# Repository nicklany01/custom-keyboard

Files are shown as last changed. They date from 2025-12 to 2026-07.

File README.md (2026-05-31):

# Custom Keyboard
## Releases
The built program can be found in github actions under the corresponding commit. There will be a file called "fireware.zip" that can be downloaded and flashed to the keyboard.
## Flashing Instructions
1. Connect the keyboard via a USB cable.
2. Double click the reset button on the keyboard (found below the rotary encoder) to enter bootloader mode. The keyboard should show up as a mass storage device on your computer.
3. Copy the "firmware.uf2" file from the downloaded release to the mass storage device to flash the keyboard. The storage device should automatically eject and the keyboard will reboot with the new firmware.
## Local Build Instructions
Source code is built in github actions using the ZMK firmware framework. To build the firmware locally, follow these steps:
1. Clone the ZMK repository using the following command:
```
git clone https://github.com/zmkfirmware/zmk.git
```
2. Set up the Zephyr SDK as described [here](https://docs.zephyrproject.org/3.5.0/develop/getting_started/index.html)
3. From the zmk directory, run the following commands to build the firmware, ensuring to replace "/path/to/this/repo/config" with the path to the config directory in this repository:
```
cd app
# To build the left side:
west build -p -b nice_nano@2.0.0 -- -DSHIELD="chirality_left nice_view_gem" -DZMK_CONFIG=/path/to/this/repo/config

# To build the right side:
west build -p -b nice_nano@2.0.0 -- -DSHIELD="chirality_right nice_view_gem" -DZMK_CONFIG=/path/to/this/repo/config
```
The built firmware file can be found at "/path/to/zmk/app/build/zephyr/zmk.uf2", and can be flashed with the [flash instructions](#flashing-instructions) above, treating "zmk.uf2" as "firmware.uf2".
For more information, see the [ZMK documentation](https://zmk.dev/docs/development/local-toolchain/setup/native) and [Zephyr documentation](https://docs.zephyrproject.org/3.5.0/develop/getting_started/index.html)

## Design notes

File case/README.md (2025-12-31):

# Case Implementation
This case is built with build123d and viewed with ocp_vscode.
## 1. Install
```bash
pip install build123d ocp_vscode
```

## 2. Start Viewer
*Ignore this section if using the OCP VSCode extension.*
Run this once to start the server in a detached tmux session:
```bash
tmux new -s viewer -d 'python -m ocp_vscode'
```
Open browser to: `http://127.0.0.1:3939`
*Note: other options are to use screen, run in background with &, suspend with ctrl z and send to background using bg, or use another terminal.*

## 3. Usage
### Dependencies
Make sure svg files required exist by running:
```sh
./case/src/export_assets.sh
```

### Run
Run the following command to update the viewer and export the build files:
```sh
python case/src/top_plate.py [-h] [--side [{left,right}]] [--thickness THICKNESS] [--extras | --no-extras] [--show | --no-show]

```

## 4. Commands
* **Run script:** `python main.py` (updates viewer)
* **Check logs:** `tmux attach -t viewer`
* **Kill server:** `tmux kill-session -t viewer`

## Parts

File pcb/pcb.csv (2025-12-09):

Reference | Qty | Value | DNP | Exclude from BOM | Exclude from Board | Footprint | Datasheet
C1,C2,C3,C4 | 4 | 100n |  |  |  | Custom Footprints:0805_2012_nonpolarised | ~
D1,D2,D3,D4,D5,D6,D7,D8,D9,D10,D11,D12,D13,D14,D15,D16,D17,D18,D19,D38,D39,D40,D41,D42,D43,D44,D45,D46,D47,D48,D49,D50,D51,D52,D53,D54,D55,D56 | 38 | 1N4148WT |  |  |  | Custom Footprints:D_SOD-523 | https://www.diodes.com/assets/Datasheets/ds30396.pdf
D20,D21,D22,D23,D24,D25,D26,D27,D28,D29,D30,D31,D32,D33,D34,D35,D36,D37,D57,D58,D59,D60,D61,D62,D63,D64,D65,D66,D67,D68,D69,D70,D71,D72,D73,D74 | 36 | SK6812 |  |  |  | Custom Footprints:SK6812_4020_SIDE_rev2 | https://cdn-shop.adafruit.com/product-files/1138/SK6812+LED+datasheet+.pdf
Display1,Display2 | 2 | nice!view |  |  |  | Custom_Footprints:nice_view | https://nicekeyboards.com/docs/nice-view/pinout-schematic
F1,F2 | 2 | Polyfuse |  |  |  | Custom Footprints:0805_2012_nonpolarised | ~
J1,J2 | 2 | Conn_01x02_Socket |  |  |  | Custom Footprints:JST_PH_S2B-PH-SM4-TB_1x02-1MP_P2.00mm_Horizontal | ~
PSW1,PSW2 | 2 | SW_SPST |  |  |  | Custom_Footprints:SW_SPDT_PCM12 | https://www.nidec-components.com/e/catalog/switch/cas.pdf
Q1,Q2 | 2 | 2N7002 |  |  |  | Custom Footprints:SOT-23-3 | https://www.onsemi.com/pub/Collateral/NDS7002A-D.PDF
R1,R2 | 2 | 100k |  |  |  | Custom Footprints:0805_2012_nonpolarised | ~
RSW1,RSW2 | 2 | SW_Push |  |  |  | Custom Footprints:SW_SPST_FSMSM | ~
SW1,SW2,SW3,SW4,SW5,SW6,SW7,SW8,SW9,SW10,SW11,SW12,SW13,SW14,SW15,SW16,SW17,SW18,SW20,SW21,SW22,SW23,SW24,SW25,SW26,SW27,SW28,SW29,SW30,SW31,SW32,SW33,SW34,SW35,SW36,SW37 | 36 | SW_Push |  |  |  | Custom Footprints:gateron-ks27-hotswap-reversible | ~
SW19,SW38 | 2 | RotaryEncoder_Switch |  |  |  | Custom Footprints:RotaryEncoder_Alps_EC11E-Switch_Vertical_H20mm | ~
U1,U2 | 2 | Sparkfun_Pro_Micro |  |  |  | Arduino:Sparkfun_Pro_Micro | https://www.sparkfun.com/products/12640

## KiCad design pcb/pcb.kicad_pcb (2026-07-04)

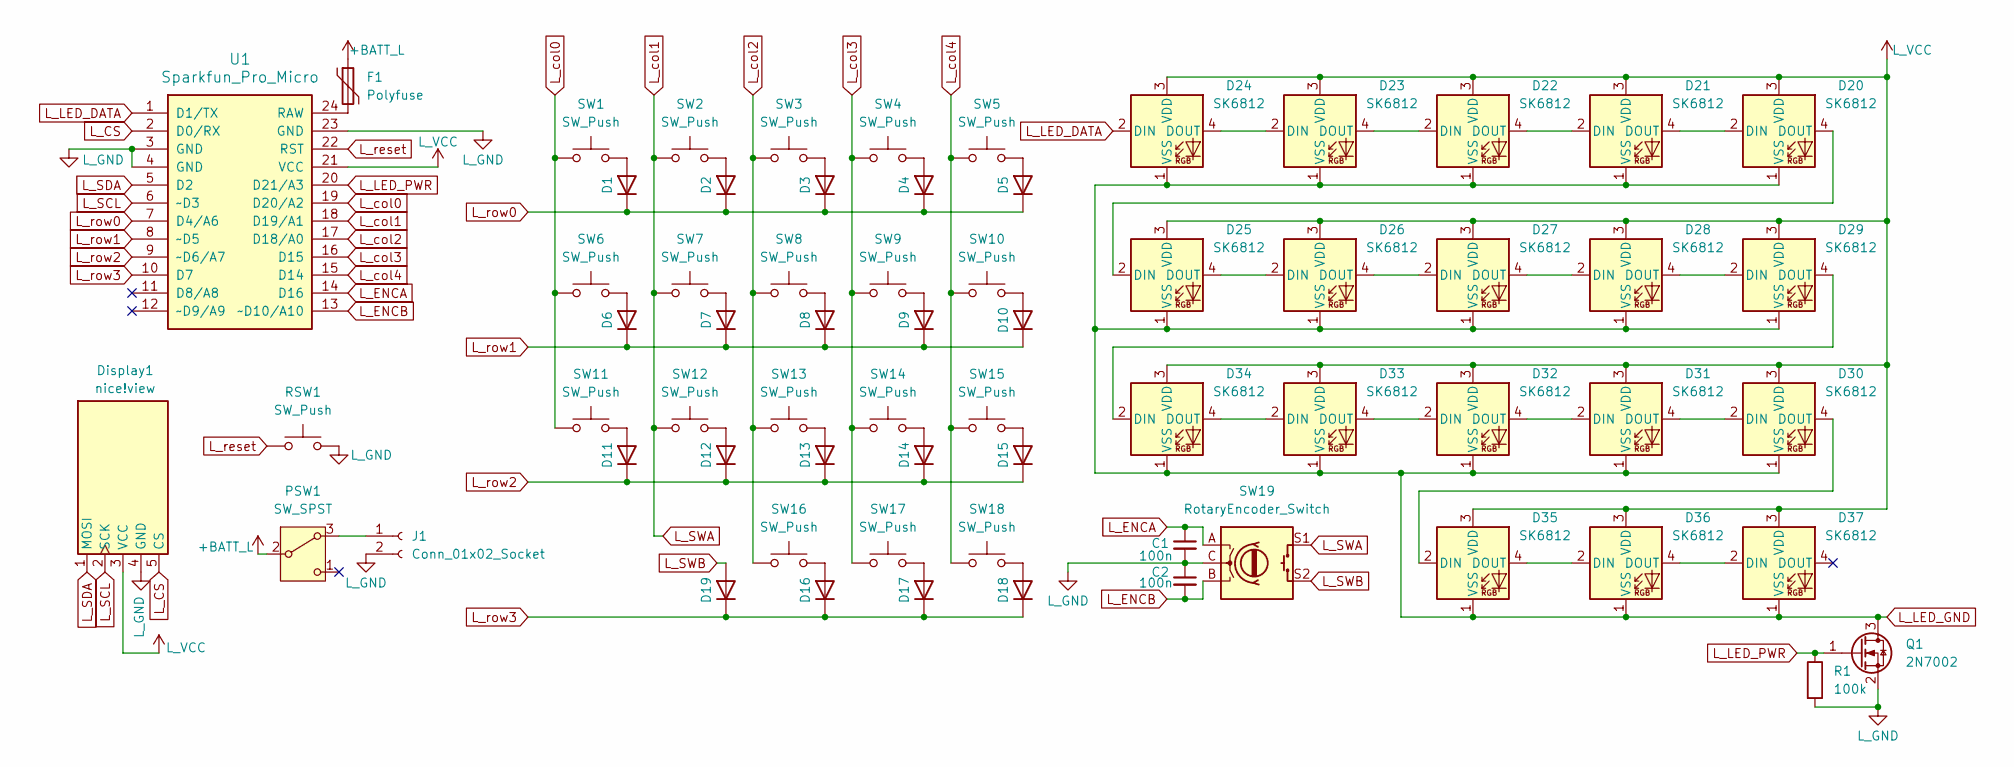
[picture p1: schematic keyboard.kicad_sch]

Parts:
C1, C2: 100n; 0805_2012_nonpolarised
D1, D2, D3, D4, D5, D6, D7, D8, D9, D10, D11, D12, D13, D14, D15, D16, D17, D18, D19: 1N4148WT; D_SOD-523
D20, D21, D22, D23, D24, D25, D26, D27, D28, D29, D30, D31, D32, D33, D34, D35, D36, D37: SK6812; SK6812_4020_SIDE_rev2
Display1: nice!view; nice_view
F1: Polyfuse; 0805_2012_nonpolarised
J1: Conn_01x02_Socket; JST_PH_S2B-PH-SM4-TB_1x02-1MP_P2.00mm_Horizontal
PSW1: SW_SPST; SW_SPDT_PCM12
Q1: 2N7002; SOT-23-3
R1: 100k; 0805_2012_nonpolarised
RSW1: SW_Push; SW_SPST_FSMSM
SW1, SW2, SW3, SW4, SW5, SW6, SW7, SW8, SW9, SW10, SW11, SW12, SW13, SW14, SW15, SW16, SW17, SW18: SW_Push; gateron-ks27-hotswap-reversible
SW19: RotaryEncoder_Switch; RotaryEncoder_Alps_EC11E-Switch_Vertical_H20mm
U1: Sparkfun_Pro_Micro

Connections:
+BATT_L: F1.1, PSW1.2 (B)
L_CS: Display1.5 (CS), U1.2 (D0/RX)
L_ENCA: C1.1, SW19.A, U1.14 (D16)
L_ENCB: C2.2, SW19.B, U1.13 (~D10/A10)
L_GND: C1.2, C2.1, Display1.4 (GND), J1.2, Q1.2 (S), R1.2, RSW1.2, SW19.C, U1.3 (GND), U1.4 (GND), U1.23 (GND)
L_LED_DATA: D24.2 (DIN), U1.1 (D1/TX)
L_LED_GND: D20.1 (VSS), D21.1 (VSS), D22.1 (VSS), D23.1 (VSS), D24.1 (VSS), D25.1 (VSS), D26.1 (VSS), D27.1 (VSS), D28.1 (VSS), D29.1 (VSS), D30.1 (VSS), D31.1 (VSS), D32.1 (VSS), D33.1 (VSS), D34.1 (VSS), D35.1 (VSS), D36.1 (VSS), D37.1 (VSS), Q1.3 (D)
L_LED_PWR: Q1.1 (G), R1.1, U1.20 (D21/A3)
L_SCL: Display1.2 (SCK), U1.6 (~D3)
L_SDA: Display1.1 (MOSI), U1.5 (D2)
L_SWA: SW2.1, SW7.1, SW12.1, SW19.S1, U1.18 (D19/A1)
L_SWB: D19.2 (A), SW19.S2
L_VCC: D20.3 (VDD), D21.3 (VDD), D22.3 (VDD), D23.3 (VDD), D24.3 (VDD), D25.3 (VDD), D26.3 (VDD), D27.3 (VDD), D28.3 (VDD), D29.3 (VDD), D30.3 (VDD), D31.3 (VDD), D32.3 (VDD), D33.3 (VDD), D34.3 (VDD), D35.3 (VDD), D36.3 (VDD), D37.3 (VDD), Display1.3 (VCC), U1.21 (VCC)
L_col0: SW1.1, SW6.1, SW11.1, U1.19 (D20/A2)
L_col2: SW3.1, SW8.1, SW13.1, SW16.1, U1.17 (D18/A0)
L_col3: SW4.1, SW9.1, SW14.1, SW17.1, U1.16 (D15)
L_col4: SW5.1, SW10.1, SW15.1, SW18.1, U1.15 (D14)
L_reset: RSW1.1, U1.22 (RST)
L_row0: D1.1 (K), D2.1 (K), D3.1 (K), D4.1 (K), D5.1 (K), U1.7 (D4/A6)
L_row1: D6.1 (K), D7.1 (K), D8.1 (K), D9.1 (K), D10.1 (K), U1.8 (~D5)
L_row2: D11.1 (K), D12.1 (K), D13.1 (K), D14.1 (K), D15.1 (K), U1.9 (~D6/A7)
L_row3: D16.1 (K), D17.1 (K), D18.1 (K), D19.1 (K), U1.10 (D7)
unnamed: D1.2 (A), SW1.2
unnamed: D2.2 (A), SW2.2
unnamed: D3.2 (A), SW3.2
unnamed: D4.2 (A), SW4.2
unnamed: D5.2 (A), SW5.2
unnamed: D6.2 (A), SW6.2
unnamed: D7.2 (A), SW7.2
unnamed: D8.2 (A), SW8.2
unnamed: D9.2 (A), SW9.2
unnamed: D10.2 (A), SW10.2
unnamed: D11.2 (A), SW11.2
unnamed: D12.2 (A), SW12.2
unnamed: D13.2 (A), SW13.2
unnamed: D14.2 (A), SW14.2
unnamed: D15.2 (A), SW15.2
unnamed: D16.2 (A), SW16.2
unnamed: D17.2 (A), SW17.2
unnamed: D18.2 (A), SW18.2
unnamed: D20.2 (DIN), D21.4 (DOUT)
unnamed: D20.4 (DOUT), D25.2 (DIN)
unnamed: D21.2 (DIN), D22.4 (DOUT)
unnamed: D22.2 (DIN), D23.4 (DOUT)
unnamed: D23.2 (DIN), D24.4 (DOUT)
unnamed: D25.4 (DOUT), D26.2 (DIN)
unnamed: D26.4 (DOUT), D27.2 (DIN)
unnamed: D27.4 (DOUT), D28.2 (DIN)
unnamed: D28.4 (DOUT), D29.2 (DIN)
unnamed: D29.4 (DOUT), D34.2 (DIN)
unnamed: D30.2 (DIN), D31.4 (DOUT)
unnamed: D30.4 (DOUT), D35.2 (DIN)
unnamed: D31.2 (DIN), D32.4 (DOUT)
unnamed: D32.2 (DIN), D33.4 (DOUT)
unnamed: D33.2 (DIN), D34.4 (DOUT)
unnamed: D35.4 (DOUT), D36.2 (DIN)
unnamed: D36.4 (DOUT), D37.2 (DIN)
unnamed: J1.1, PSW1.3 (A)
unnamed: F1.2, U1.24 (RAW)

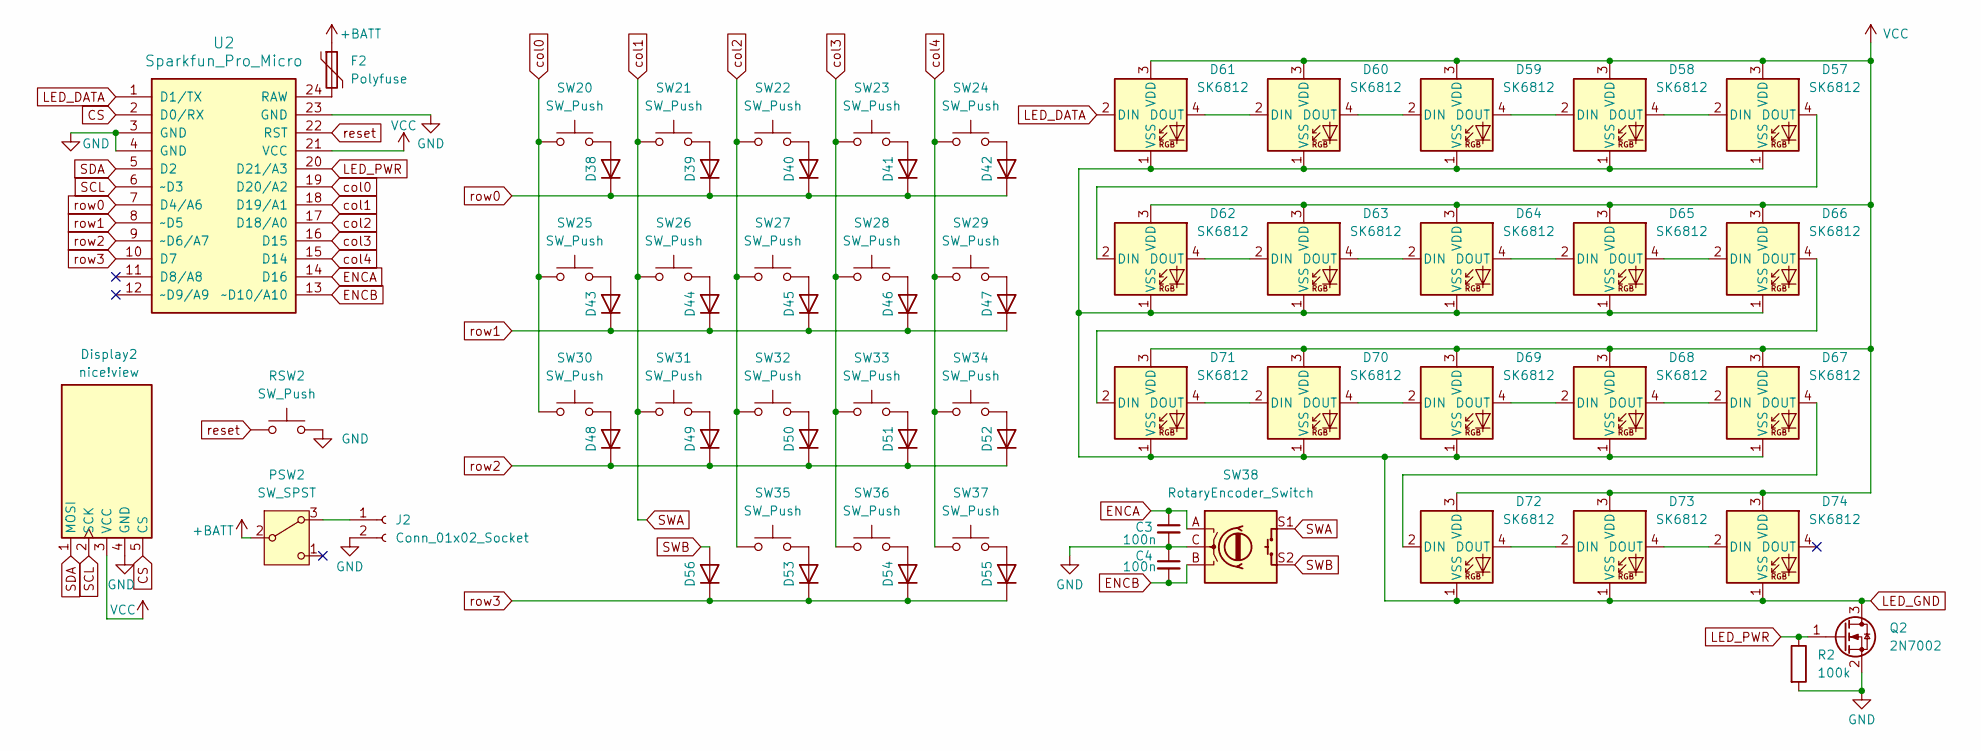
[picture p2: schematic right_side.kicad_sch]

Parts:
C3, C4: 100n; 0805_2012_nonpolarised
D38, D39, D40, D41, D42, D43, D44, D45, D46, D47, D48, D49, D50, D51, D52, D53, D54, D55, D56: 1N4148WT; D_SOD-523
D57, D58, D59, D60, D61, D62, D63, D64, D65, D66, D67, D68, D69, D70, D71, D72, D73, D74: SK6812; SK6812_4020_SIDE_rev2
Display2: nice!view; nice_view
F2: Polyfuse; 0805_2012_nonpolarised
J2: Conn_01x02_Socket; JST_PH_S2B-PH-SM4-TB_1x02-1MP_P2.00mm_Horizontal
PSW2: SW_SPST; SW_SPDT_PCM12
Q2: 2N7002; SOT-23-3
R2: 100k; 0805_2012_nonpolarised
RSW2: SW_Push; SW_SPST_FSMSM
SW20, SW21, SW22, SW23, SW24, SW25, SW26, SW27, SW28, SW29, SW30, SW31, SW32, SW33, SW34, SW35, SW36, SW37: SW_Push; gateron-ks27-hotswap-reversible
SW38: RotaryEncoder_Switch; RotaryEncoder_Alps_EC11E-Switch_Vertical_H20mm
U2: Sparkfun_Pro_Micro

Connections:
+BATT: F2.1, PSW2.2 (B)
CS: Display2.5 (CS), U2.2 (D0/RX)
ENCA: C3.1, SW38.A, U2.14 (D16)
ENCB: C4.2, SW38.B, U2.13 (~D10/A10)
GND: C3.2, C4.1, Display2.4 (GND), J2.2, Q2.2 (S), R2.2, RSW2.2, SW38.C, U2.3 (GND), U2.4 (GND), U2.23 (GND)
LED_DATA: D61.2 (DIN), U2.1 (D1/TX)
LED_GND: D57.1 (VSS), D58.1 (VSS), D59.1 (VSS), D60.1 (VSS), D61.1 (VSS), D62.1 (VSS), D63.1 (VSS), D64.1 (VSS), D65.1 (VSS), D66.1 (VSS), D67.1 (VSS), D68.1 (VSS), D69.1 (VSS), D70.1 (VSS), D71.1 (VSS), D72.1 (VSS), D73.1 (VSS), D74.1 (VSS), Q2.3 (D)
LED_PWR: Q2.1 (G), R2.1, U2.20 (D21/A3)
unnamed: D38.2 (A), SW20.2
unnamed: D39.2 (A), SW21.2
unnamed: D40.2 (A), SW22.2
unnamed: D41.2 (A), SW23.2
unnamed: D42.2 (A), SW24.2
unnamed: D43.2 (A), SW25.2
unnamed: D44.2 (A), SW26.2
unnamed: D45.2 (A), SW27.2
unnamed: D46.2 (A), SW28.2
unnamed: D47.2 (A), SW29.2
unnamed: D48.2 (A), SW30.2
unnamed: D49.2 (A), SW31.2
unnamed: D50.2 (A), SW32.2
unnamed: D51.2 (A), SW33.2
unnamed: D52.2 (A), SW34.2
unnamed: D53.2 (A), SW35.2
unnamed: D54.2 (A), SW36.2
unnamed: D55.2 (A), SW37.2
unnamed: D57.2 (DIN), D58.4 (DOUT)
unnamed: D57.4 (DOUT), D62.2 (DIN)
unnamed: D58.2 (DIN), D59.4 (DOUT)
unnamed: D59.2 (DIN), D60.4 (DOUT)
unnamed: D60.2 (DIN), D61.4 (DOUT)
unnamed: D62.4 (DOUT), D63.2 (DIN)
unnamed: D63.4 (DOUT), D64.2 (DIN)
unnamed: D64.4 (DOUT), D65.2 (DIN)
unnamed: D65.4 (DOUT), D66.2 (DIN)
unnamed: D66.4 (DOUT), D71.2 (DIN)
unnamed: D67.2 (DIN), D68.4 (DOUT)
unnamed: D67.4 (DOUT), D72.2 (DIN)
unnamed: D68.2 (DIN), D69.4 (DOUT)
unnamed: D69.2 (DIN), D70.4 (DOUT)
unnamed: D70.2 (DIN), D71.4 (DOUT)
unnamed: D72.4 (DOUT), D73.2 (DIN)
unnamed: D73.4 (DOUT), D74.2 (DIN)
unnamed: J2.1, PSW2.3 (A)
unnamed: F2.2, U2.24 (RAW)
SCL: Display2.2 (SCK), U2.6 (~D3)
SDA: Display2.1 (MOSI), U2.5 (D2)
SWA: SW21.1, SW26.1, SW31.1, SW38.S1, U2.18 (D19/A1)
SWB: D56.2 (A), SW38.S2
VCC: D57.3 (VDD), D58.3 (VDD), D59.3 (VDD), D60.3 (VDD), D61.3 (VDD), D62.3 (VDD), D63.3 (VDD), D64.3 (VDD), D65.3 (VDD), D66.3 (VDD), D67.3 (VDD), D68.3 (VDD), D69.3 (VDD), D70.3 (VDD), D71.3 (VDD), D72.3 (VDD), D73.3 (VDD), D74.3 (VDD), Display2.3 (VCC), U2.21 (VCC)
col0: SW20.1, SW25.1, SW30.1, U2.19 (D20/A2)
col2: SW22.1, SW27.1, SW32.1, SW35.1, U2.17 (D18/A0)
col3: SW23.1, SW28.1, SW33.1, SW36.1, U2.16 (D15)
col4: SW24.1, SW29.1, SW34.1, SW37.1, U2.15 (D14)
reset: RSW2.1, U2.22 (RST)
row0: D38.1 (K), D39.1 (K), D40.1 (K), D41.1 (K), D42.1 (K), U2.7 (D4/A6)
row1: D43.1 (K), D44.1 (K), D45.1 (K), D46.1 (K), D47.1 (K), U2.8 (~D5)
row2: D48.1 (K), D49.1 (K), D50.1 (K), D51.1 (K), D52.1 (K), U2.9 (~D6/A7)
row3: D53.1 (K), D54.1 (K), D55.1 (K), D56.1 (K), U2.10 (D7)

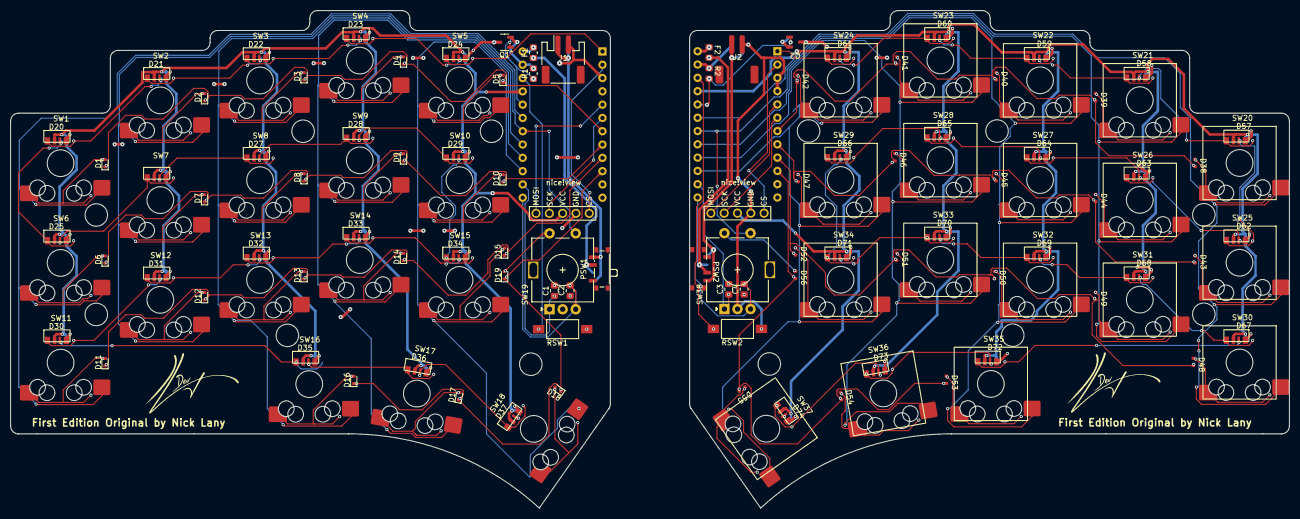
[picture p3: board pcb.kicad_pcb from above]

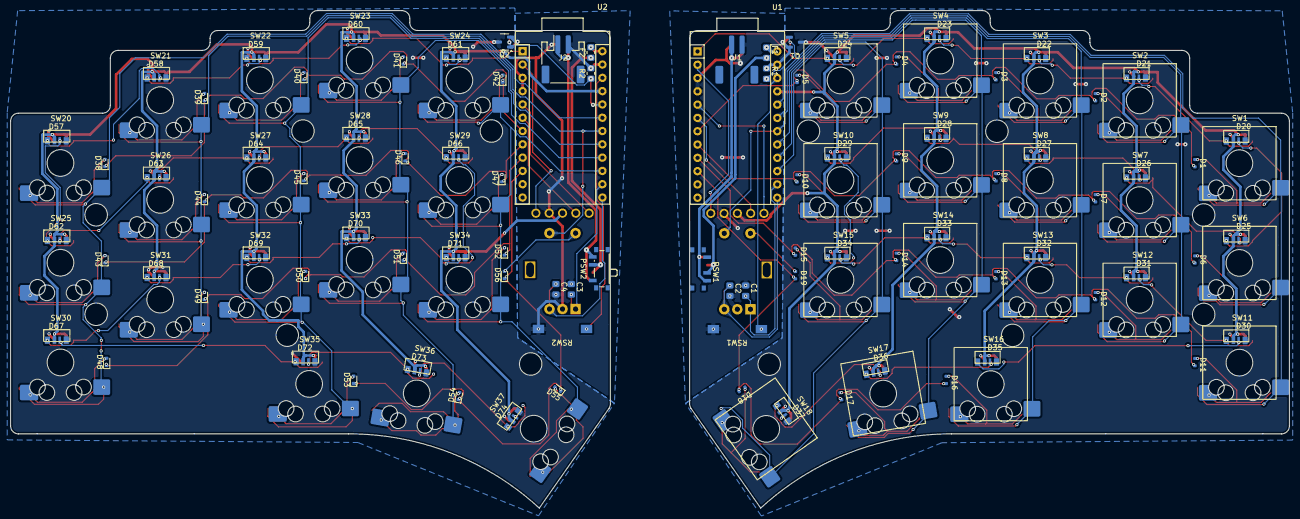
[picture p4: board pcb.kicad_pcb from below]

Board: 2 copper layers, 244.3 x 95.0 mm, 132 parts (62 on the bottom side), 118 nets.

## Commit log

2025-10-30 Add PCB
    [keyboard.kicad_sch, pcb.kicad_pcb, pcb.kicad_sch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]
2025-12-09 Add basic keyboard layout
    [pcb.csv, pcb.kicad_pcb]
2025-12-09 Remove old schematics
    [keyboard.kicad_sch, right_side.kicad_sch]
2025-12-10 Revert "Remove old schematics"
    This reverts commit 279f44eda0d01da2331cf1d736d6b6c595c70e90.
    I fucked up. These schematics were part of the hierarchical schematics
    and are needed.
    [keyboard.kicad_sch, right_side.kicad_sch]
2025-12-11 Add rotary encoder functionality
2025-12-31 Add case files and documentation
    [pcb.kicad_pcb]
2025-12-31 Add finished top plate
    Modified pcb layers to be exportable.
    Added export script to export svg files
    Completed top plate design
    [pcb.kicad_pcb]
2026-01-01 Fix top plate screw hole size
2026-01-01 Add cutout for dev board on top plate
    [pcb.kicad_pcb]
2026-01-01 Add basic case shape
2026-05-16 Make case tilt, walls and battery compartment
2026-05-16 Adjust dimensions to match physical keyboard, and add battery resting platform
2026-05-16 Add wiring cutout to allow battery to connect to pcb
2026-05-19 Add offset around case for smoother fit, add charger and switch cutouts
2026-05-30 Add adjustments to tent angle and switch cutout
2026-05-30 add top screen case pcb outlines
    [pcb.kicad_pcb]
2026-05-31 add top case part to fit in top
2026-05-31 Add clearances for slotting parts
2026-05-31 adjust screw holes and battery cutout
2026-06-14 change stl export to step file
2026-06-15 change direction of right rotary encoder, add mouse
2026-06-18 change zmk rgb leds to sleep after 15 mins even when plugged in
2026-07-04 update case tolerances
    [pcb.kicad_pcb]
